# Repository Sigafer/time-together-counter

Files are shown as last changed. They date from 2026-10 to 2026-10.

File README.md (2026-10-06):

# Time-Together Counter

A pocket-watch-sized PCB that shows time passed, from a past moment, in the format `YY:DDD:HH:MM:SS`. The 1.3" OLED (SH1106 128×64 I²C) stays dark until someone double-taps the device. It runs standalone from a small LiPo charged over USB-C every few months.

Designed in Altium Designer by Zsigmond Csaba.

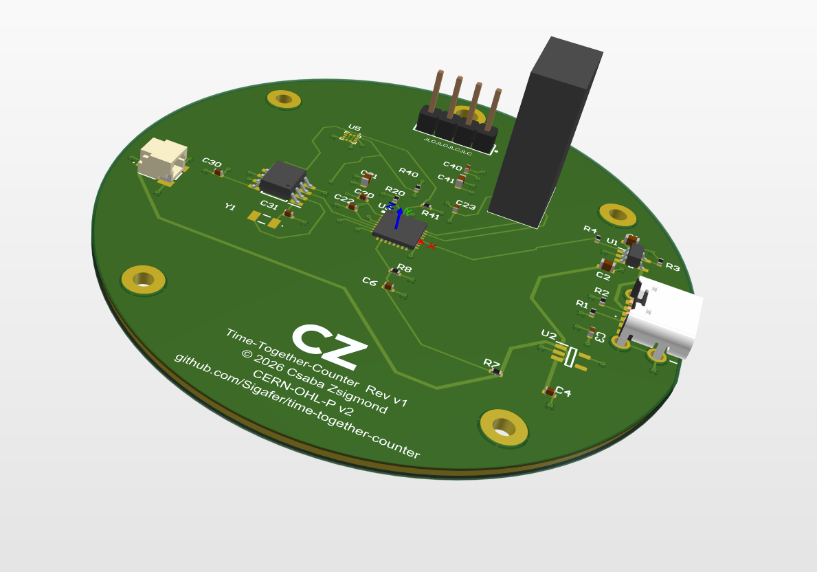
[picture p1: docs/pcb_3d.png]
PCB 3D view


> [!TIP]
> **Schematic and PCB layout:** no Altium needed. Open the PDFs in the [`docs`](docs/) folder:
> - 📄 [Schematic (PDF)](docs/schematic.pdf)
> - 📄 [PCB layout (PDF)](docs/layout.pdf)
> - 📋 [Bill of materials (CSV)](docs/BOM.csv)

## How it works

A low-power STM32 sleeps until the accelerometer detects a double-tap in hardware. It then reads the real-time clock, computes the time elapsed since a fixed start timestamp, and shows it on the OLED for about 5 seconds before going back to sleep. The RTC keeps counting the whole time, so the count survives resets and never drifts more than a few seconds per year.

| Block | Part | Notes |
| --- | --- | --- |
| MCU | STM32L031K6U6 | ~1 µA in Stop mode, programmed over SWD (TC2030) |
| Real-time clock | Micro Crystal RV-3028-C7 | 1 Hz tick on CLKOUT, very low drift |
| Wake on double-tap | ST LIS2DW12 | Tap detection in hardware, INT1 wakes the MCU |
| Display | 1.3" 128×64 SH1106 I²C OLED module | Always on 3V3, put to sleep between taps |
| Charger | Microchip MCP73831 (4.2 V) | 100 mA charge current, status read by the MCU |
| Regulator | TI TPS7A0233 (3.3 V) | 25 nA quiescent current |
| Battery | 502030 protected LiPo, ~250 mAh | JST SH 2-pin connector |
| Charging port | GCT USB4125-GF-A | USB-C, power only (5.6k CC pull-downs) |

### I²C addresses

| Device | Address |
| --- | --- |
| RV-3028-C7 (RTC) | 0x52 |
| LIS2DW12 (accelerometer) | 0x18 |

## Repository layout

```
hardware/altium/            Altium project: .PrjPcb and .SchDoc
hardware/altium/libraries/  component libraries used by the project (.SchLib, .PcbLib)
hardware/production/        Gerbers, BOM and pick-and-place files (later)
firmware/                   STM32 firmware (later)
docs/                       schematic PDF and other documentation
artwork/                    line art for the black art side of the board (later)
mechanical/                 3D-printed back cover (later)
```

## License

   Copyright 2026 Csaba Zsigmond

   This hardware design is licensed under the CERN Open Hardware Licence
   Version 2 – Permissive (CERN-OHL-P v2). See [LICENSE](LICENSE).

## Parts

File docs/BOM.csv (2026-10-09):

Comment | Description | Designator | Footprint | Quantity | Manufacturer | Manufacturer Part Number | LCSC | Fitted
4.7uF | Ceramic capacitor 4.7uF 10V X5R 0603 | C1, C2, C21 | 0603 | 3 | Yageo | CC0603KRX5R6BB475 | C109456 | Yes
1uF | Ceramic capacitor 1uF 25V X5R 0402 | C3, C4 | 0402 | 2 | Samsung Electro-Mechanics | CL05A105KA5NQNC | C52923 | Yes
100nF | Ceramic capacitor 100nF 16V X7R 0402 | C6, C20, C22, C23, C30, C40 | 0402 | 6 | Yageo | CC0402KRX7R7BB104 | C60474 | Yes
10uF | Ceramic capacitor 10uF 10V X5R 0603 | C41 | 0603 | 1 | Samsung Electro-Mechanics | CL10A106KP8NNNC | C19702 | Yes
20pF C0G | Ceramic capacitor 20pF 50V C0G 0402, RTC crystal load (OSCI) | C31 | 0402 | 1 | FH | 0402CG200J500NT | C1554 | Yes
5.1k | Resistor 5.1k 1% 0402, USB-C CC pull-down | R1, R2 | 0402 | 2 | UNI-ROYAL | 0402WGF5101TCE | C25905 | Yes
10k | Resistor 10k 1% 0402 | R3, R4, R20 | 0402 | 3 | UNI-ROYAL | 0402WGF1002TCE | C25744 | Yes
1M | Resistor 1M 1% 0402, battery divider | R7, R8 | 0402 | 2 | UNI-ROYAL | 0402WGF1004TCE | C26083 | Yes
4.7k | Resistor 4.7k 1% 0402, I2C pull-up | R40, R41 | 0402 | 2 | UNI-ROYAL | 0402WGF4701TCE | C25900 | Yes
MCP73831T-2ACI/OT | LiPo charger 4.2V, 100mA | U1 | SOT-23-5 | 1 | Microchip | MCP73831T-2ACI/OT | C424093 | Yes
TPS7A0233DBVR | LDO 3.3V 200mA, 25nA Iq | U2 | SOT-23-5 | 1 | Texas Instruments | TPS7A0233DBVR | C5142805 | Yes
STM32L031K6U6 | MCU Cortex-M0+ 32kB flash | U3 | UFQFPN-32 5x5 | 1 | STMicroelectronics | STM32L031K6U6TR | C2969821 | Yes
BM8563ESA | RTC I2C (PCF8563-compatible) | U4 | SOP-8 | 1 | Gatemode | BM8563ESA | C269877 | Yes
LIS2DW12TR | Accelerometer, double-tap wake | U5 | LGA-12 2x2 | 1 | STMicroelectronics | LIS2DW12TR | C189624 | Yes
32.768kHz 12.5pF | Crystal 32.768kHz 12.5pF +/-20ppm | Y1 | 3215 (3.2x1.5mm) | 1 | Epson | Q13FC13500004 | C32346 | Yes
USB4125-GF-A | USB-C receptacle, power only (6P) | J1 | USB4125-GF-A | 1 | GCT | USB4125-GF-A | C3151650 | Yes
SM02B-SRSS-TB(LF)(SN) | JST SH 2-pin side entry, LiPo | J2 | SM02B-SRSS-TB | 1 | JST | SM02B-SRSS-TB(LF)(SN) | C160402 | Yes
TC2030-IDC-NL | SWD programming pads (no part, cable only) | J3 | TC2030-IDC-NL | 1 | Tag-Connect | TC2030-IDC-NL |  | No
OLED header | 1x4 2.54mm header, comes with SH1106 OLED module, hand-soldered | J4 | 1x4 THT 2.54mm | 1 |  |  |  | No

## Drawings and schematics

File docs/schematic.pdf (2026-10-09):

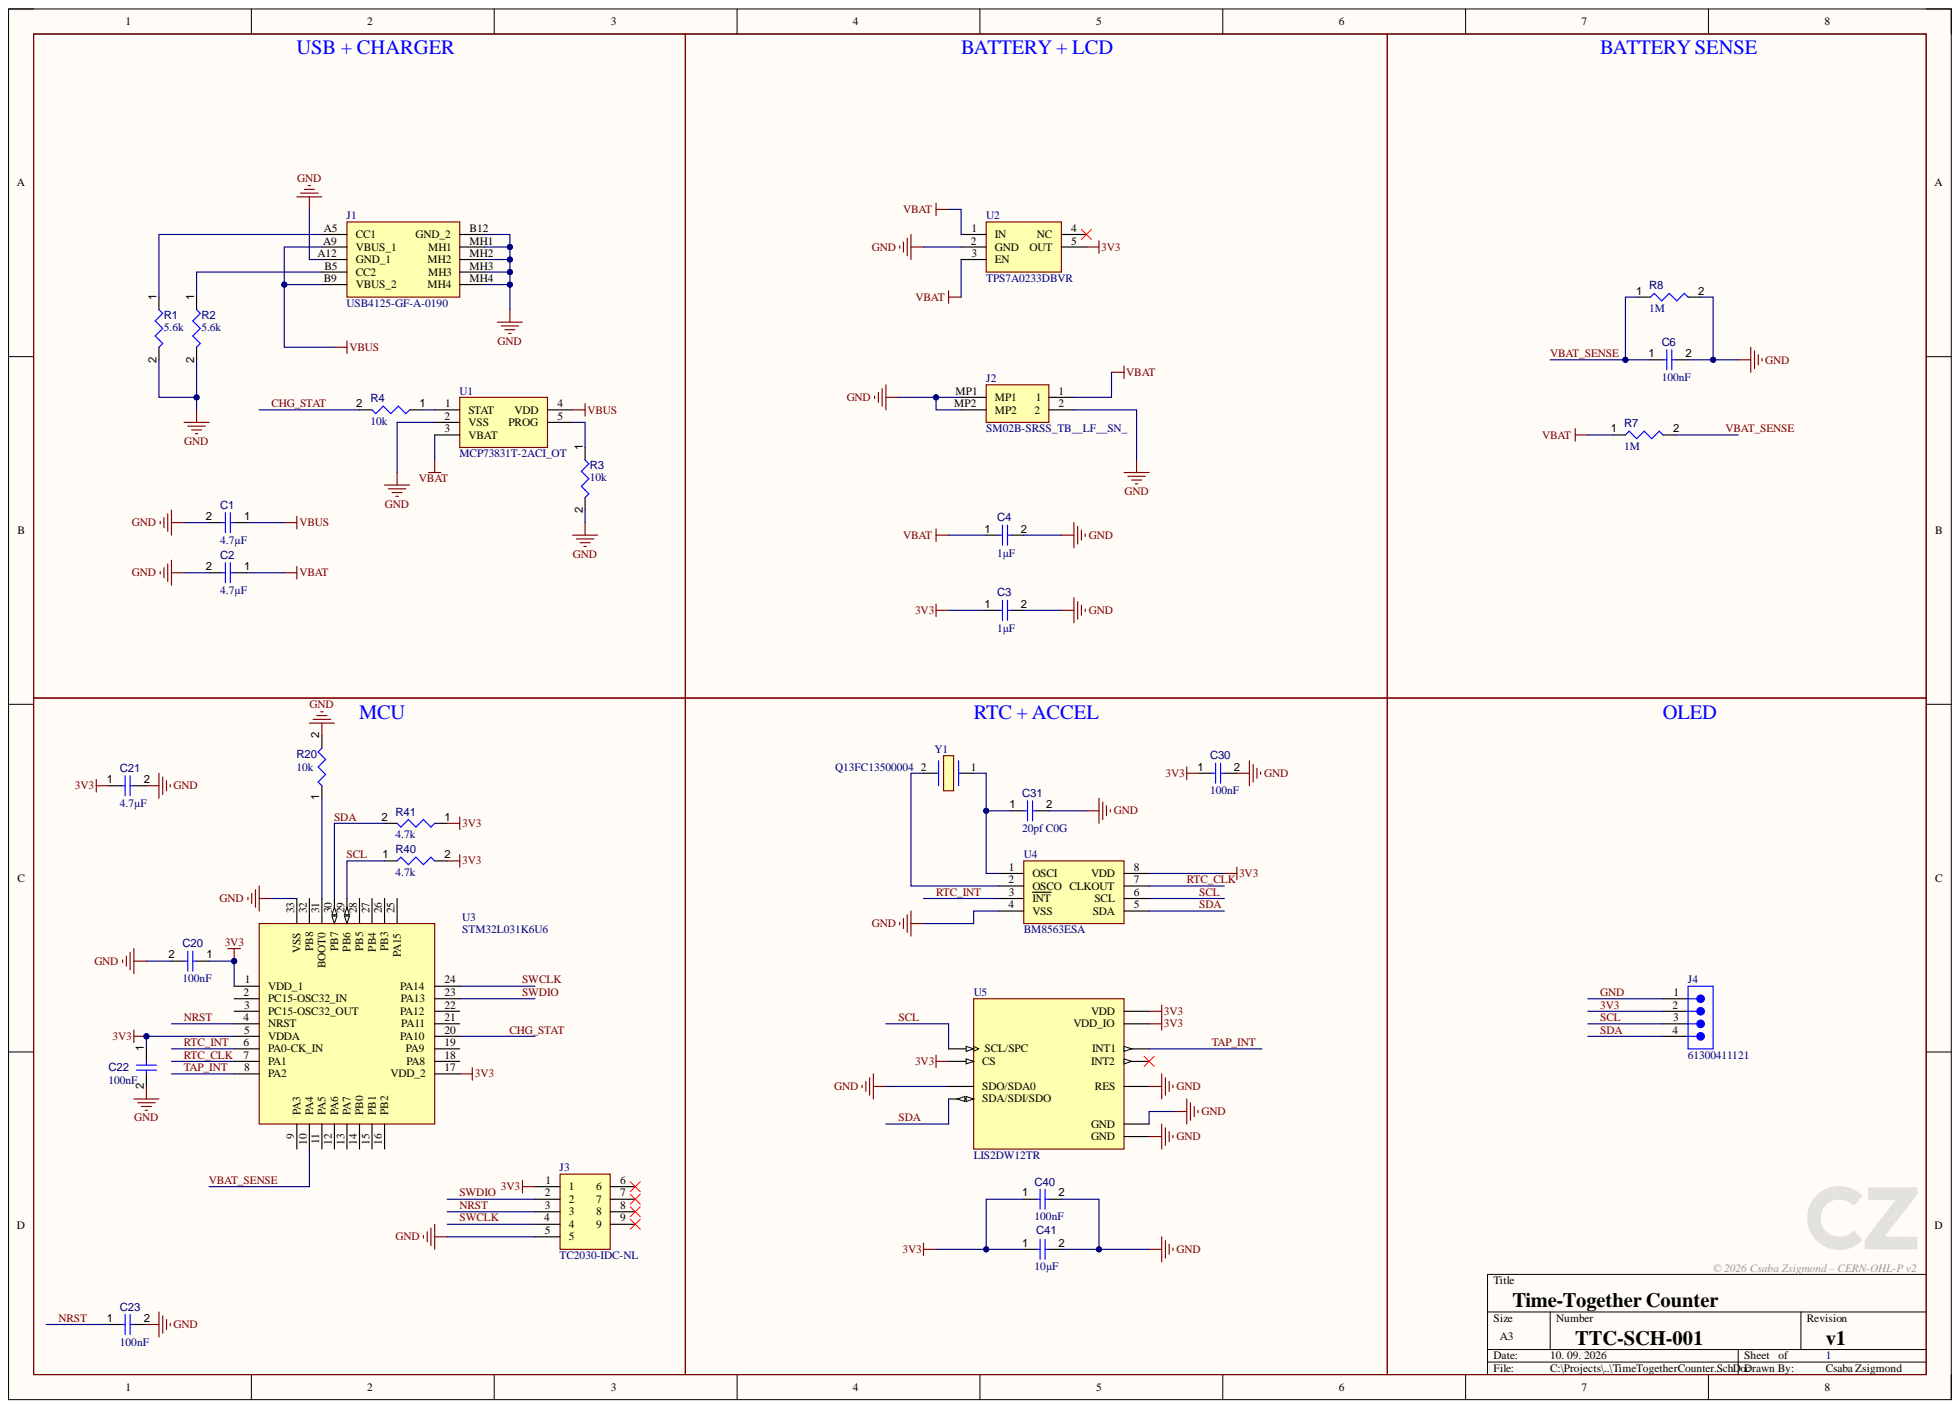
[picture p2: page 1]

© 2026 Csaba Zsigmond – CERN-OHL-P v2

Size A3 | Number TTC-SCH-001 | Revision v1

Date: 10. 09. 2026 | Sheet of 1
File: C:\Projects\..\TimeTogetherCounter.SchDoDc rawn By: | Csaba Zsigmond

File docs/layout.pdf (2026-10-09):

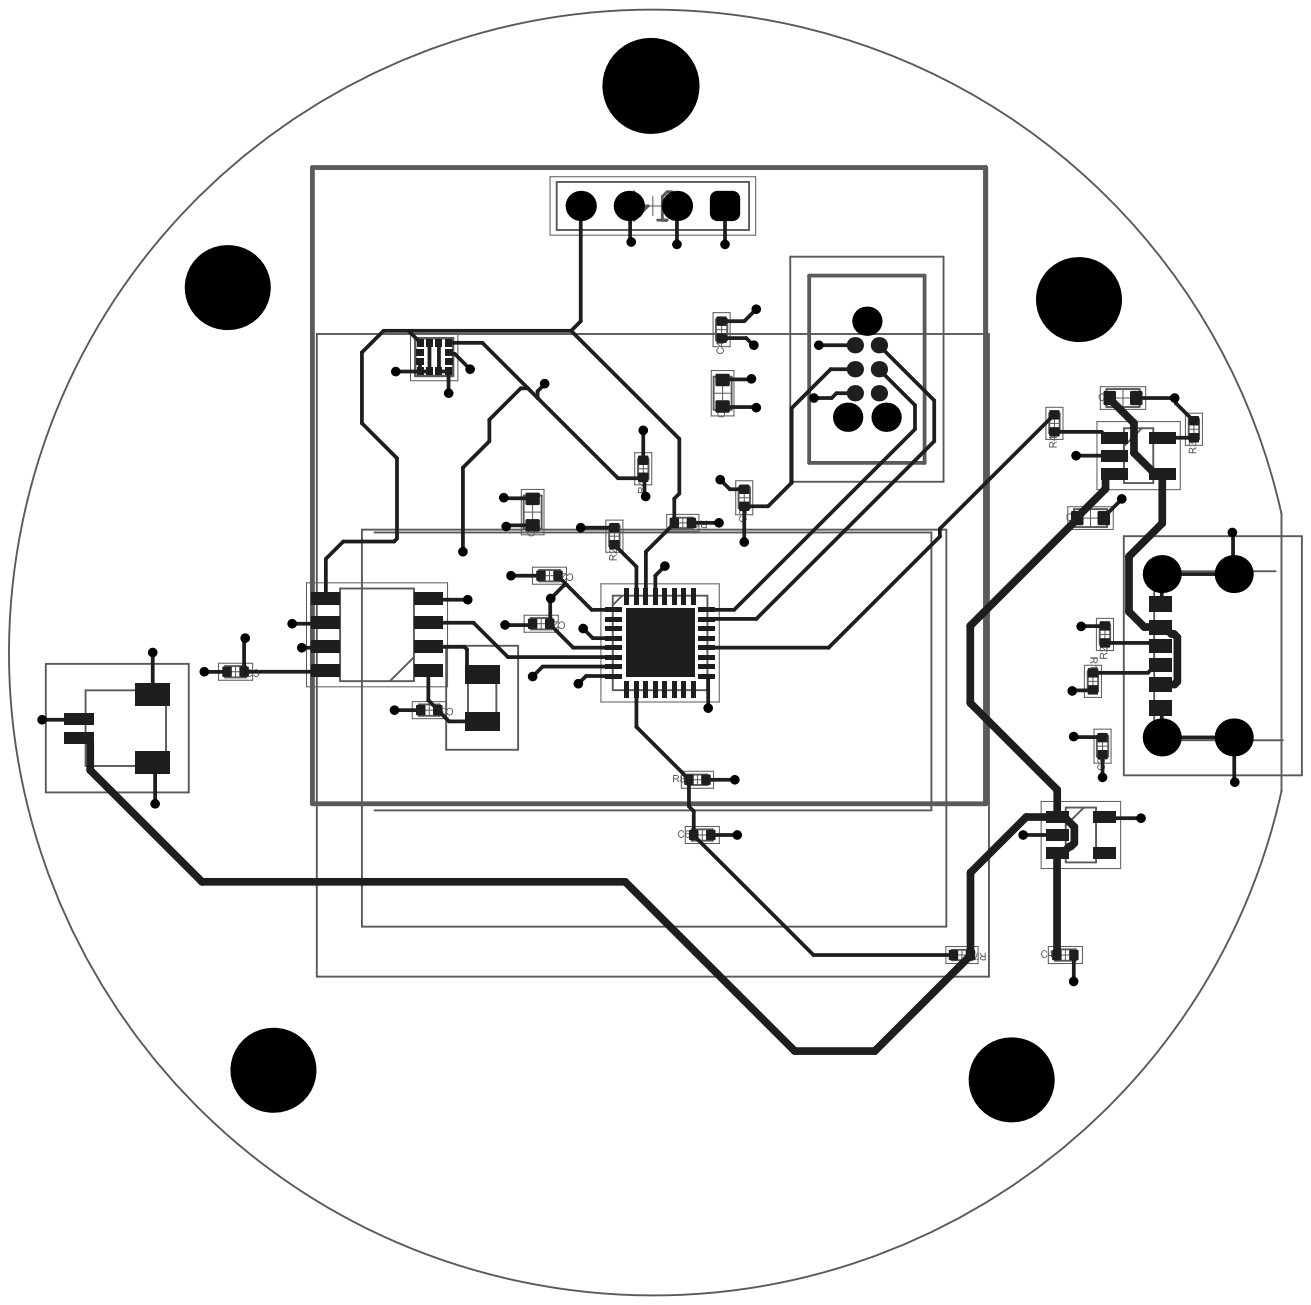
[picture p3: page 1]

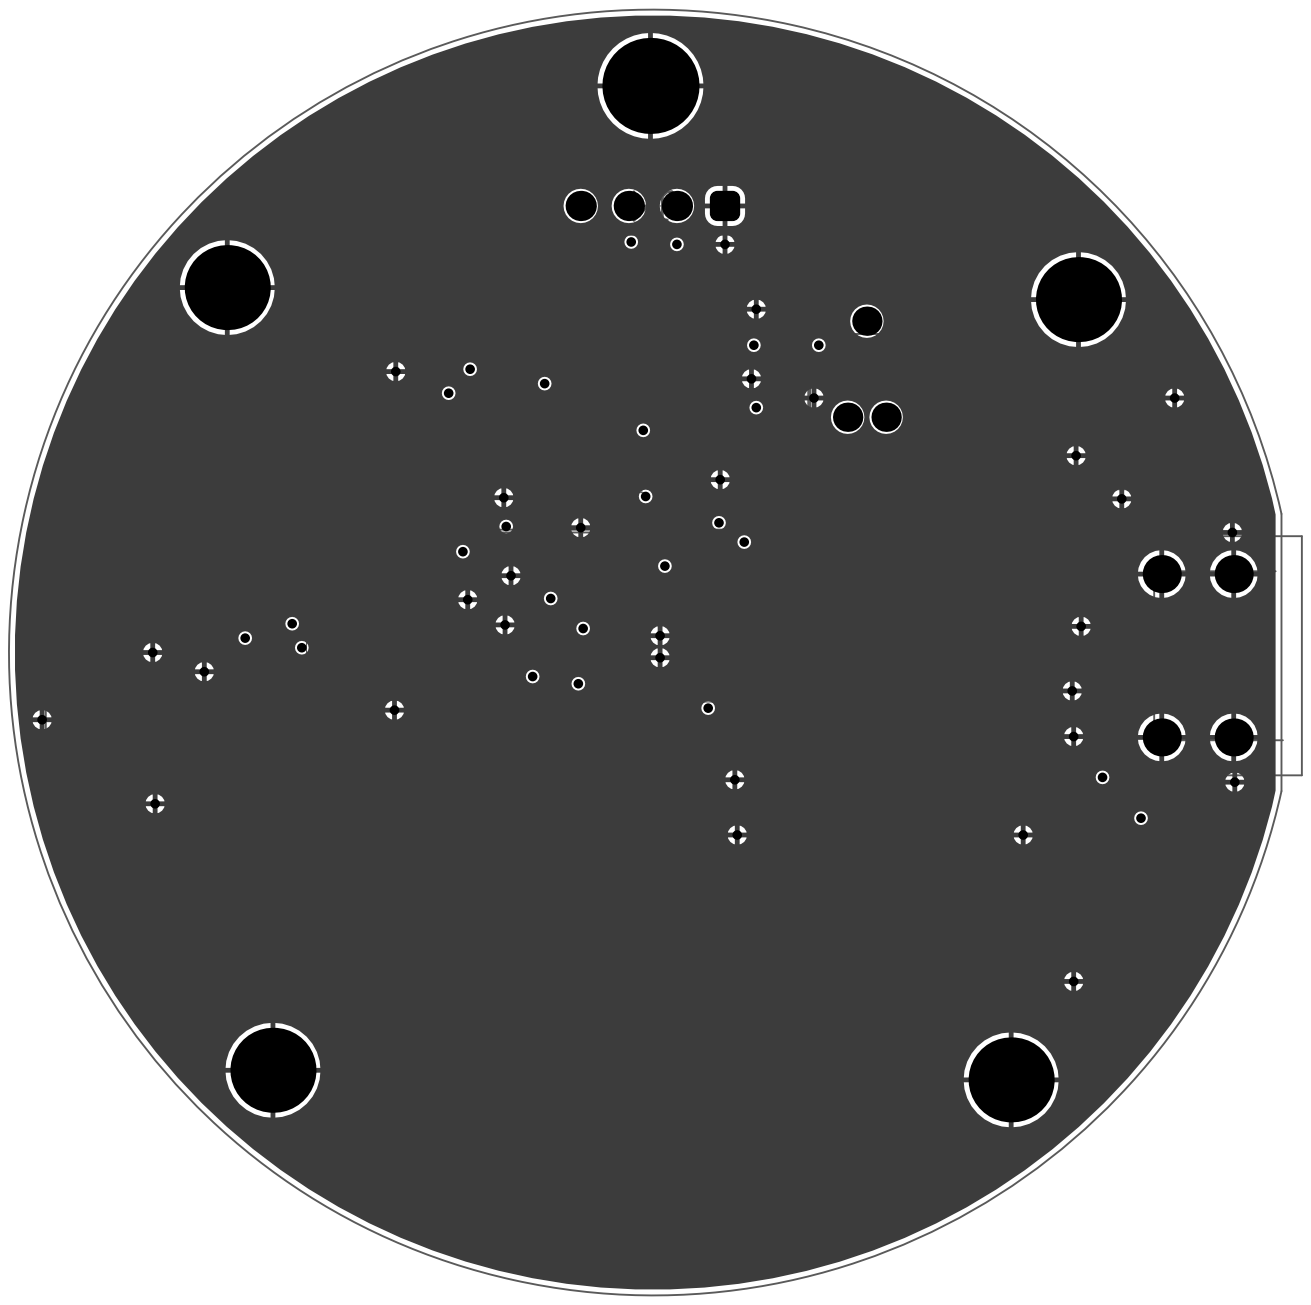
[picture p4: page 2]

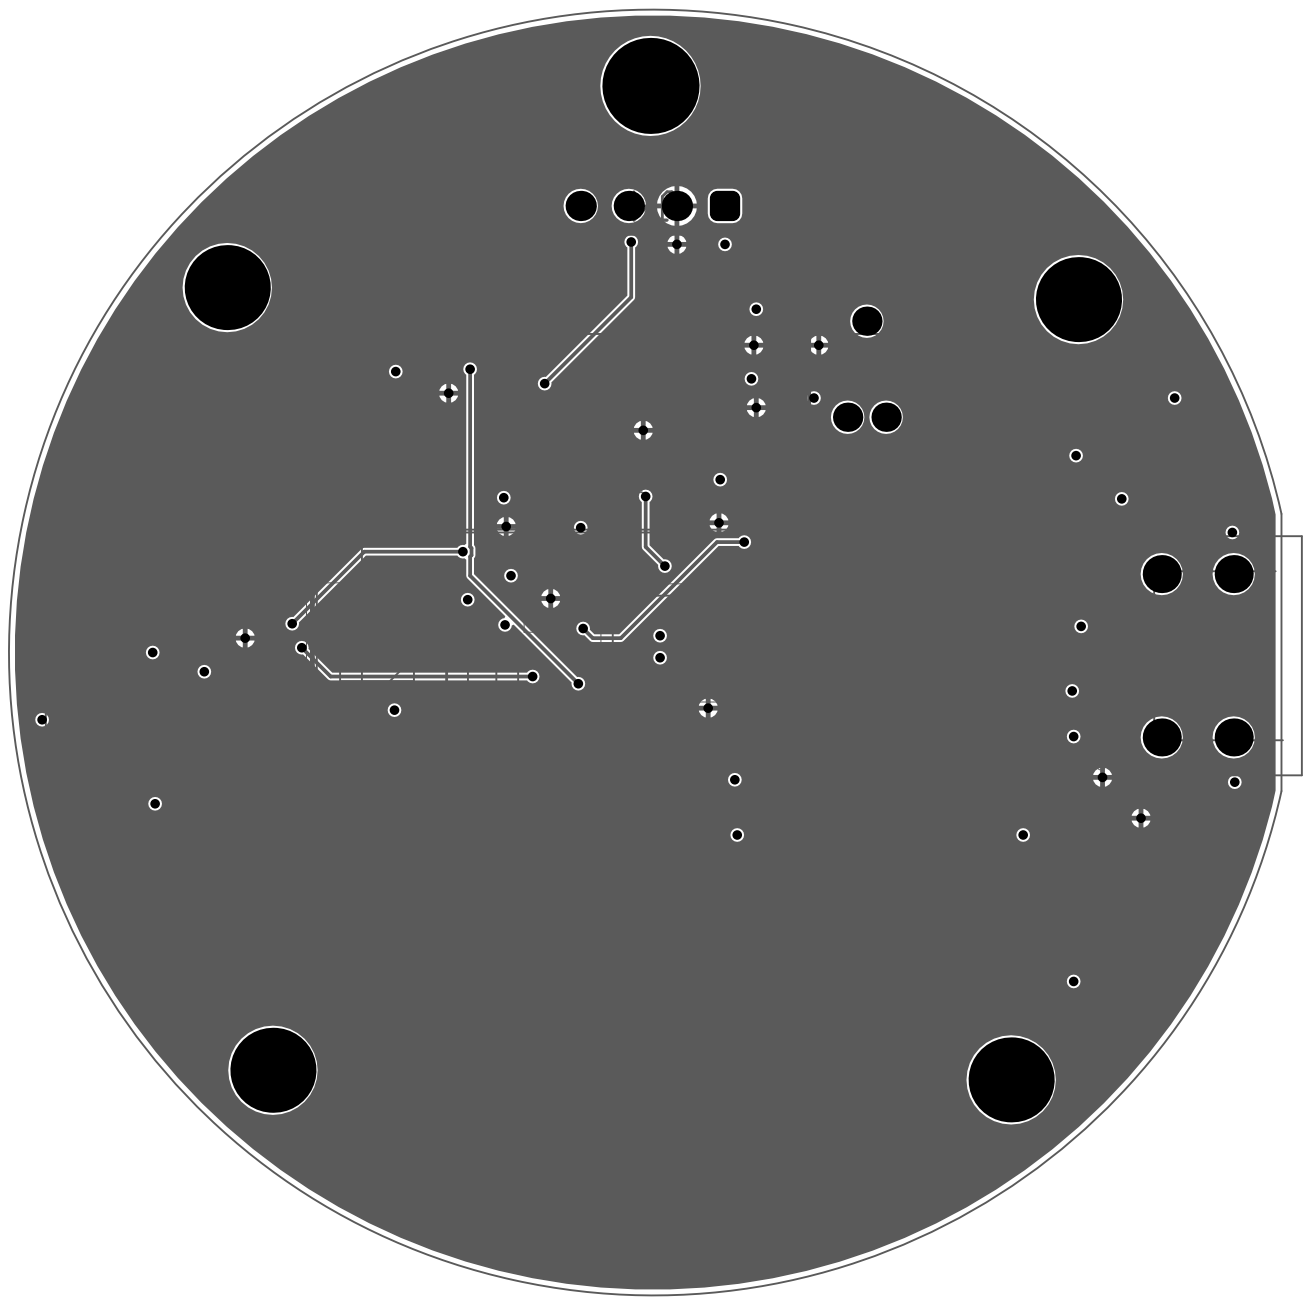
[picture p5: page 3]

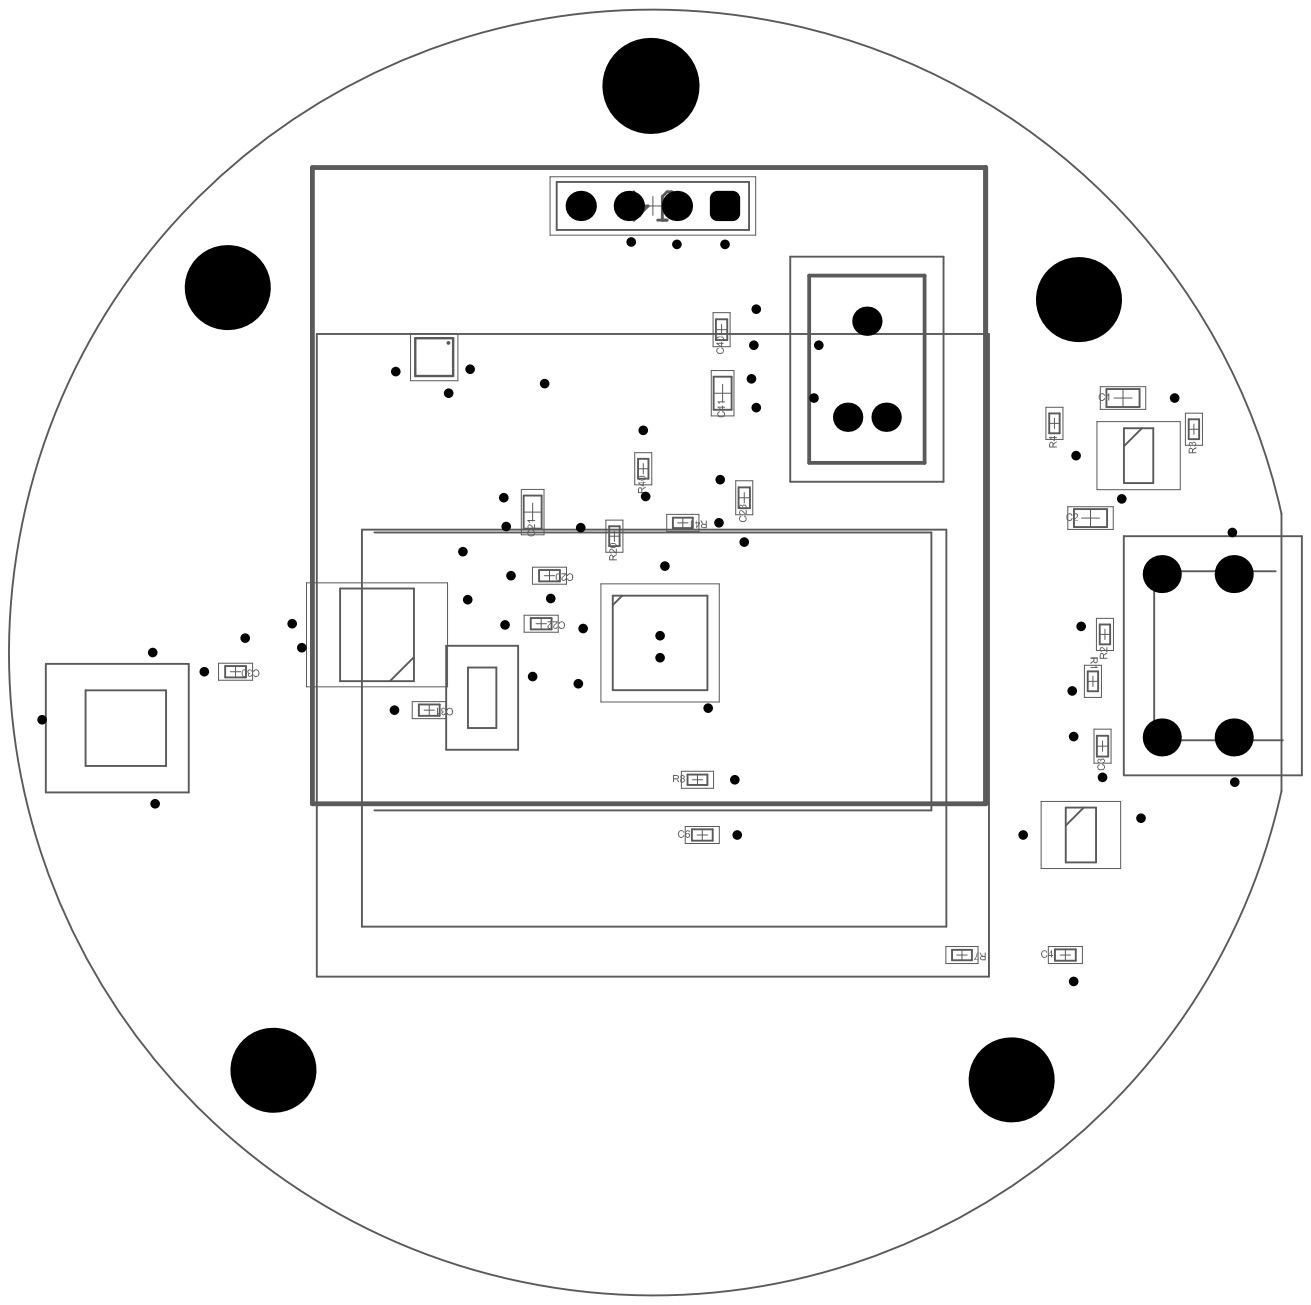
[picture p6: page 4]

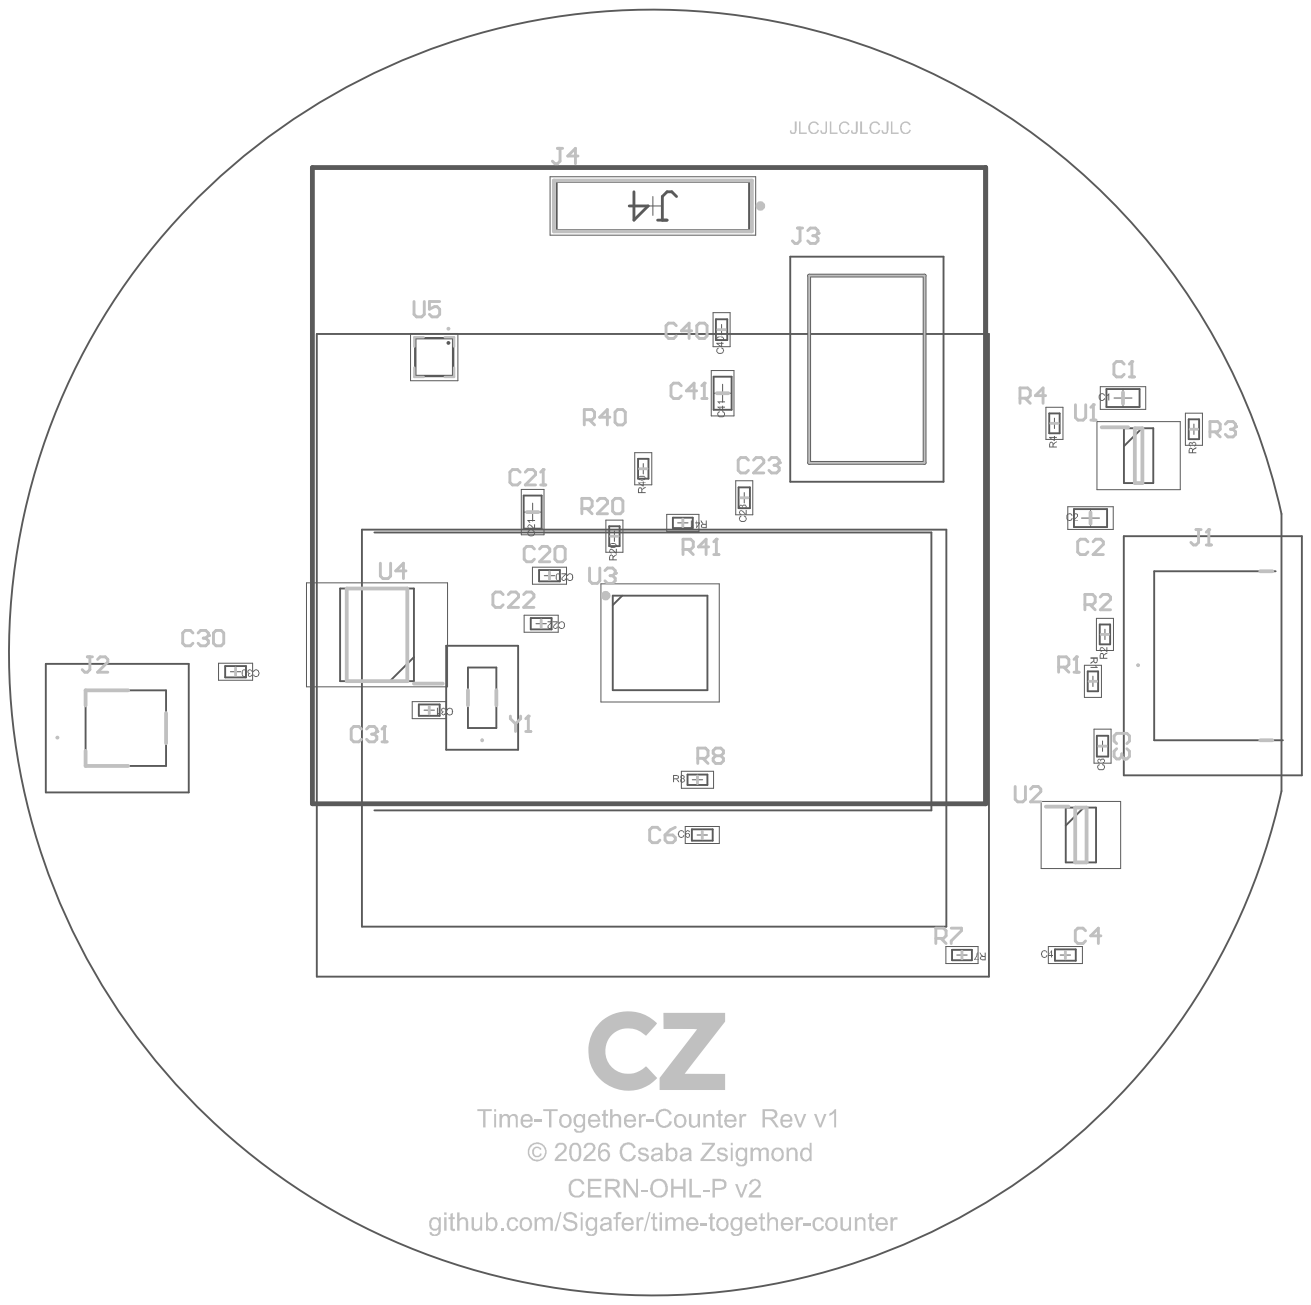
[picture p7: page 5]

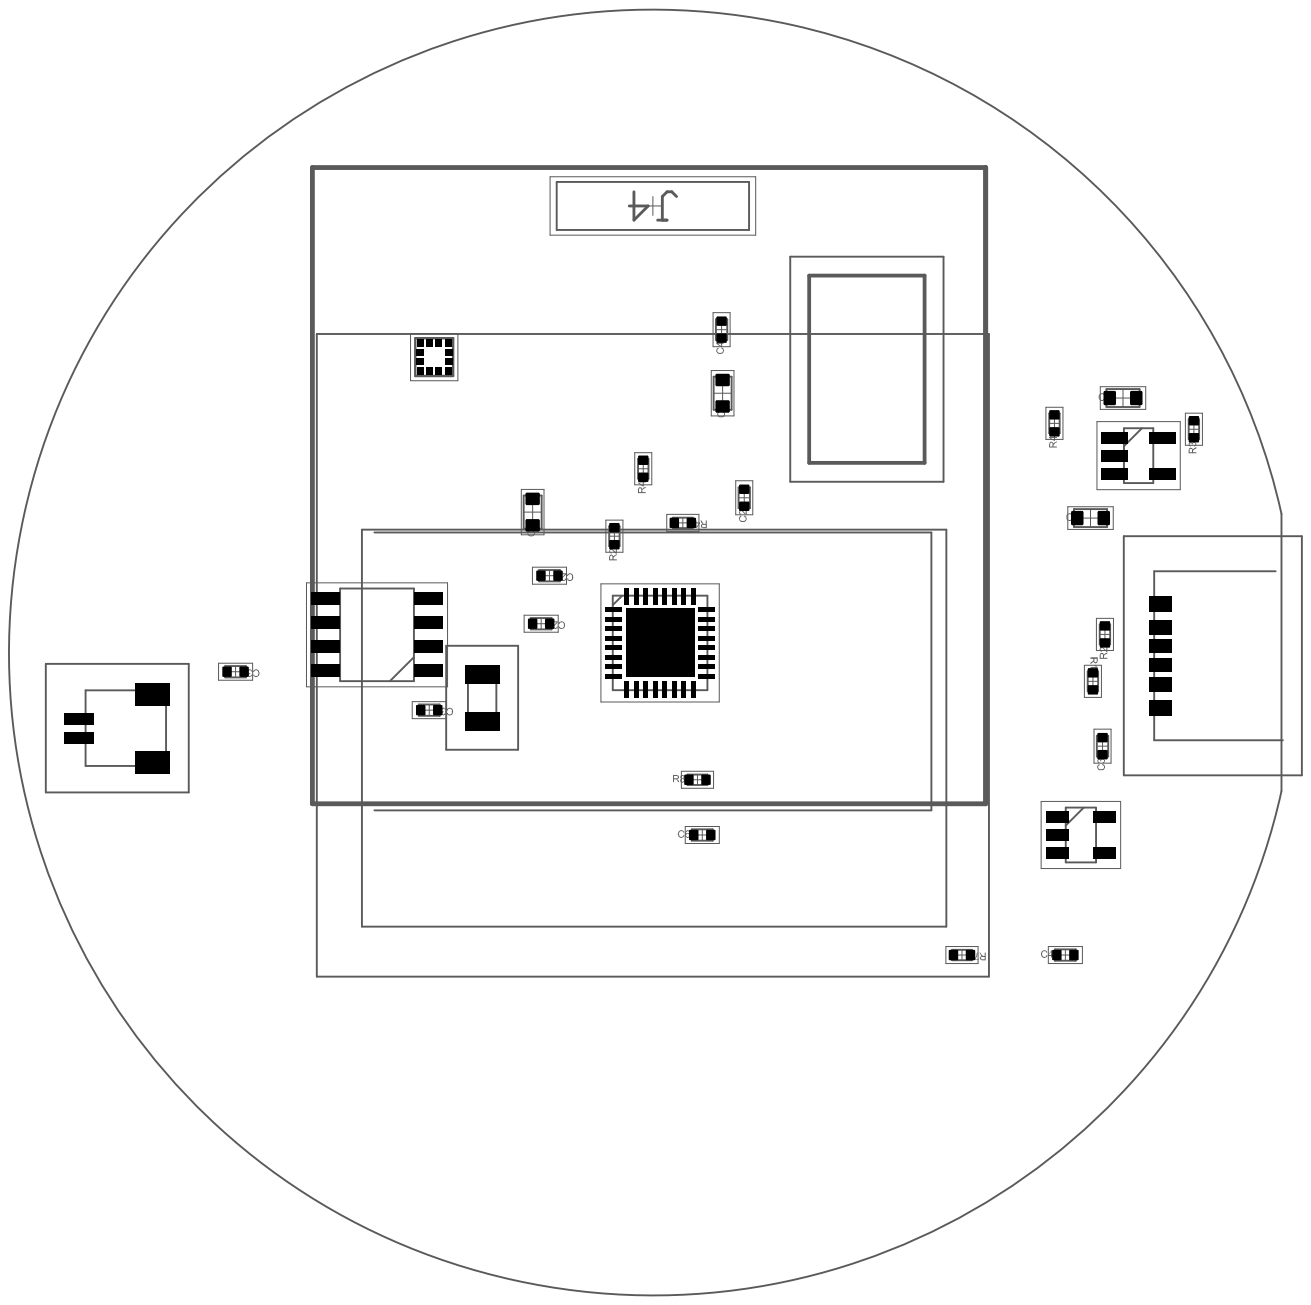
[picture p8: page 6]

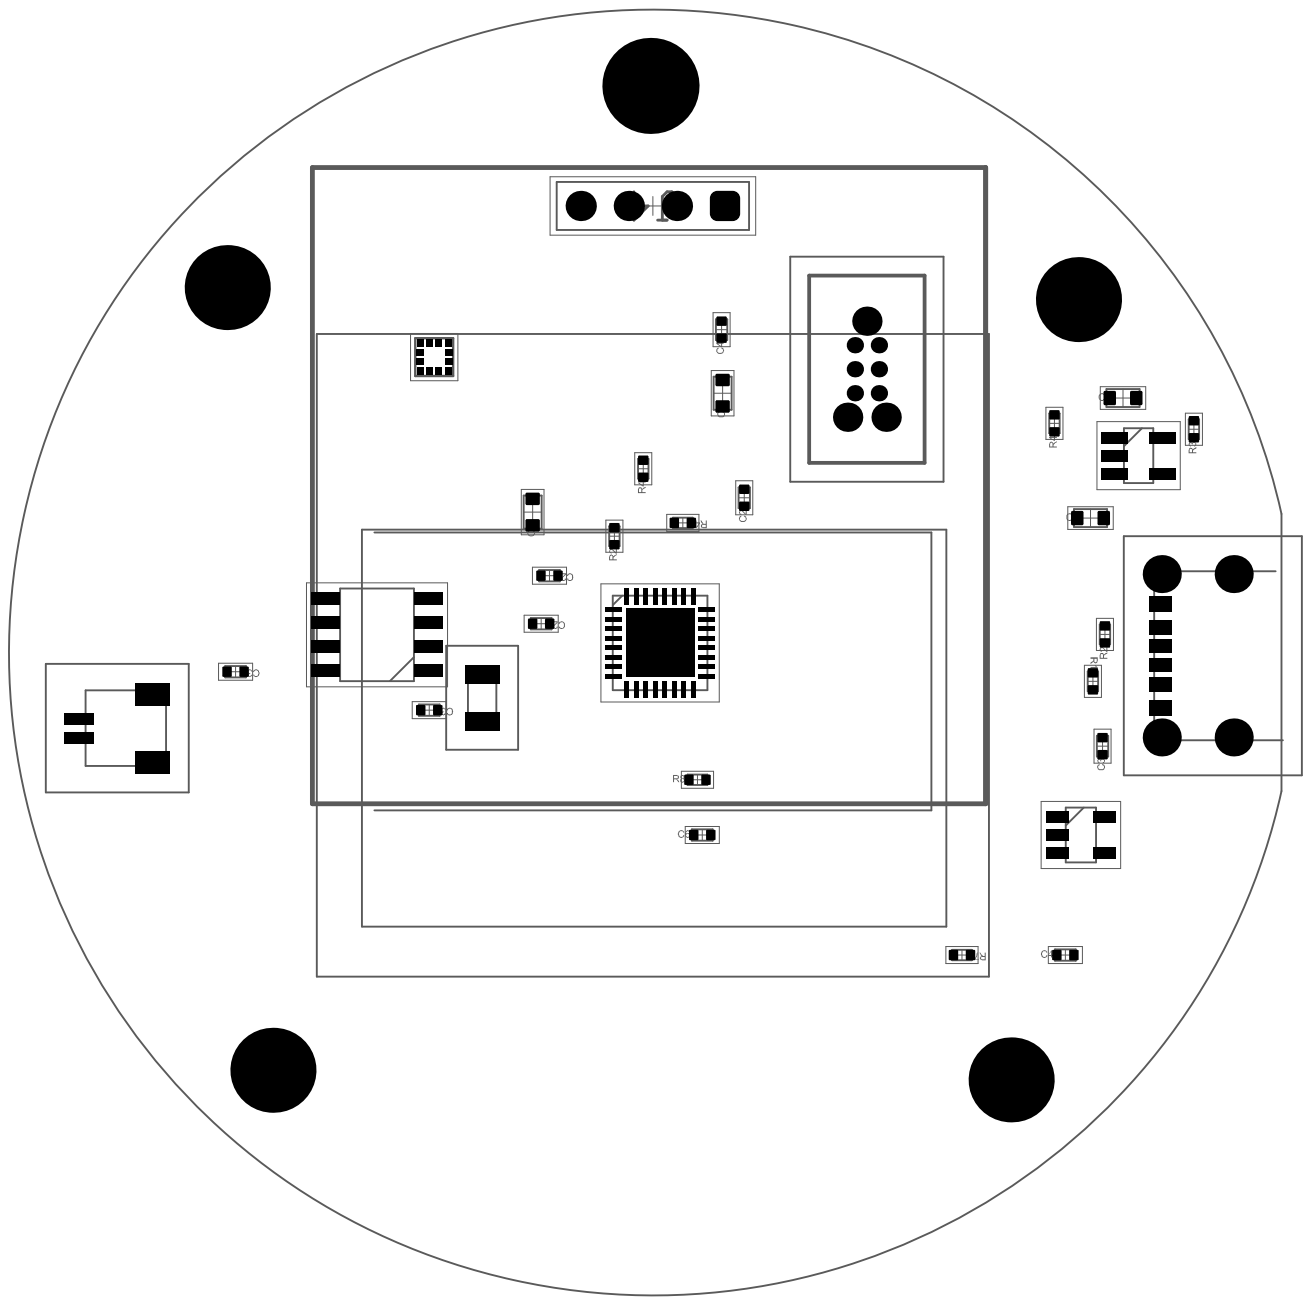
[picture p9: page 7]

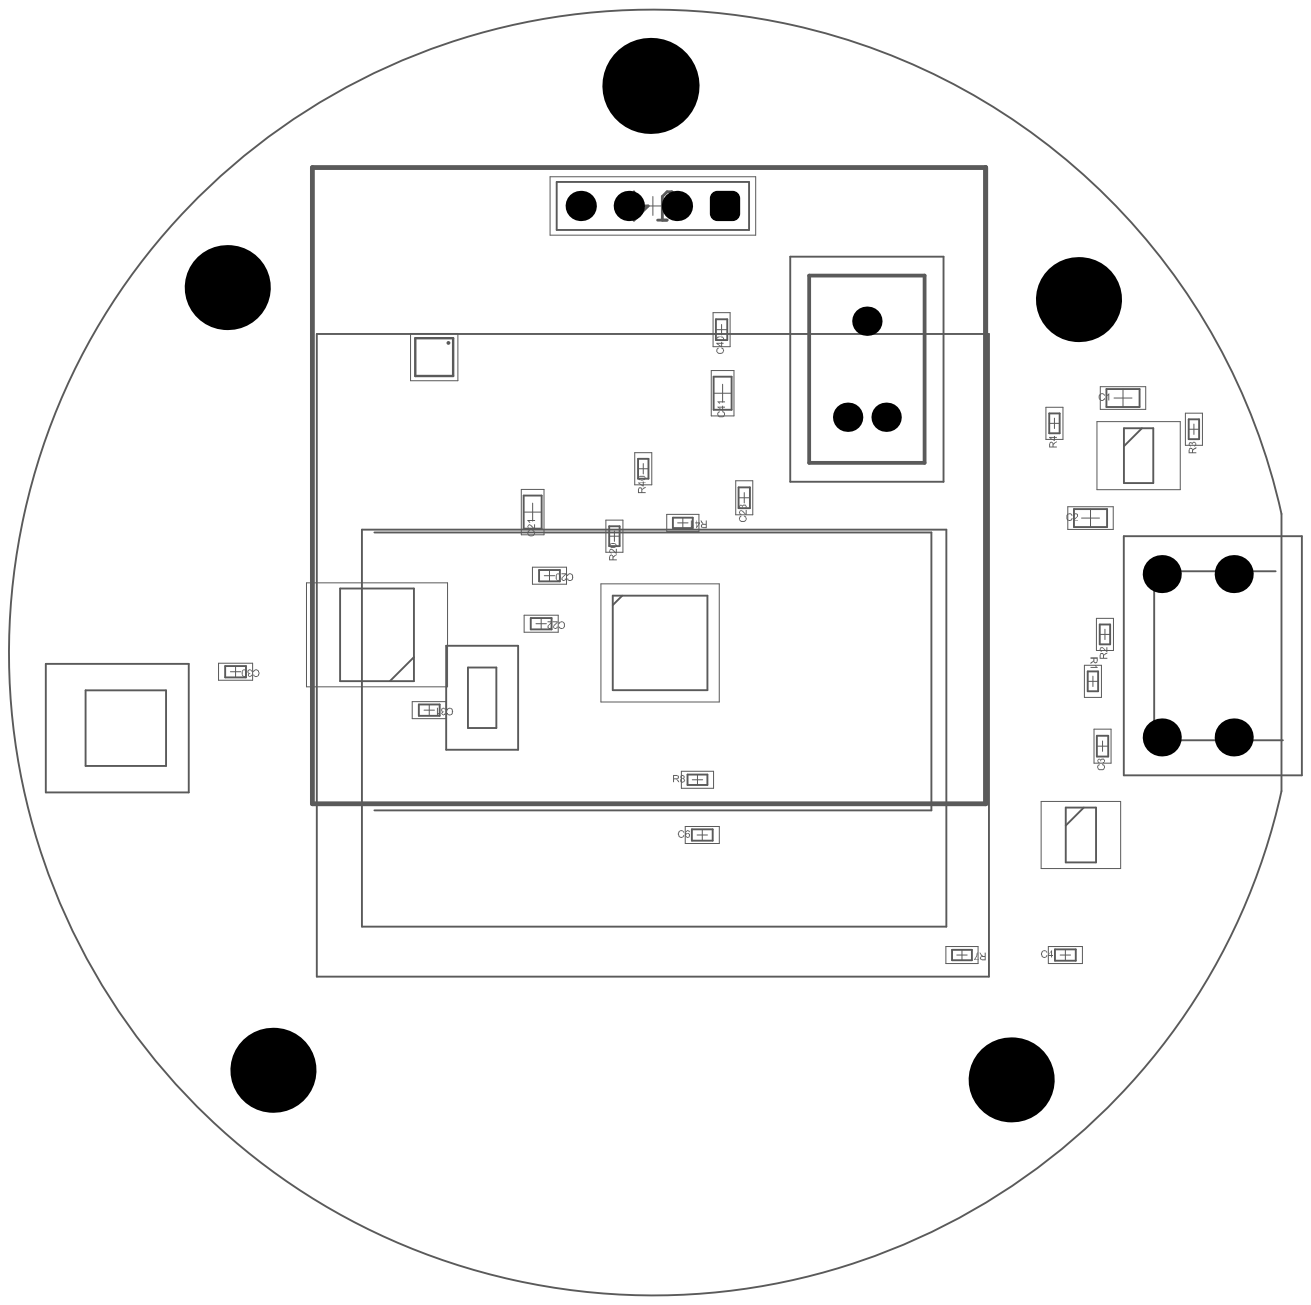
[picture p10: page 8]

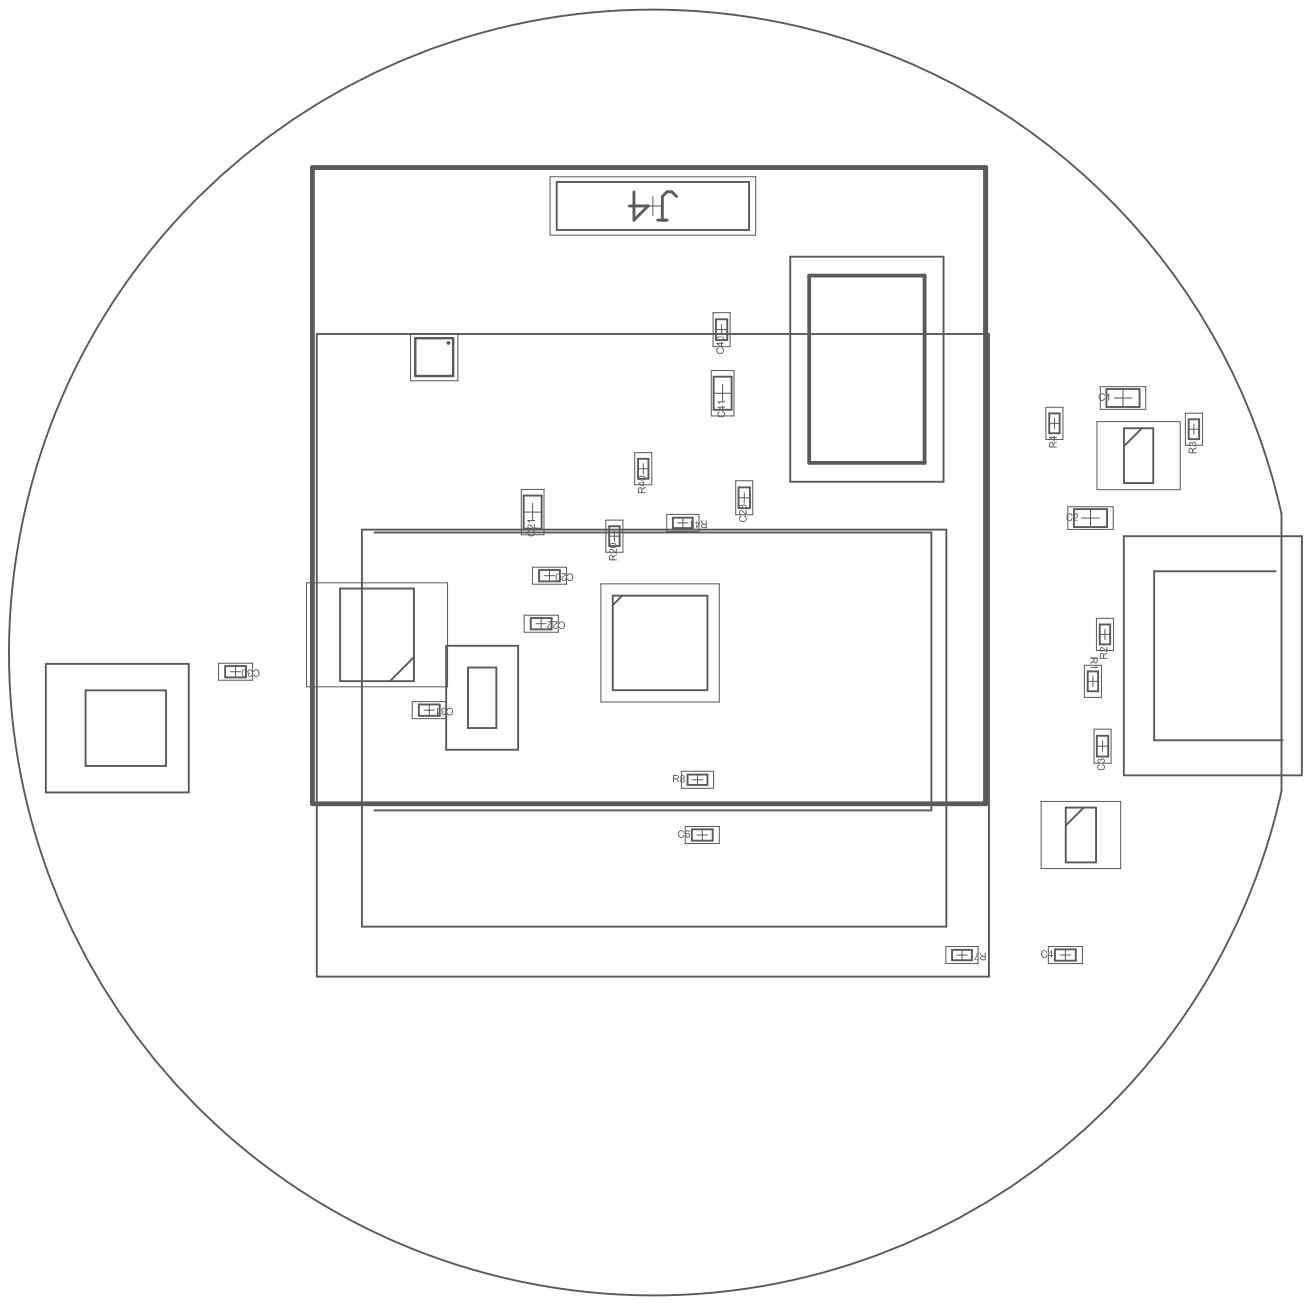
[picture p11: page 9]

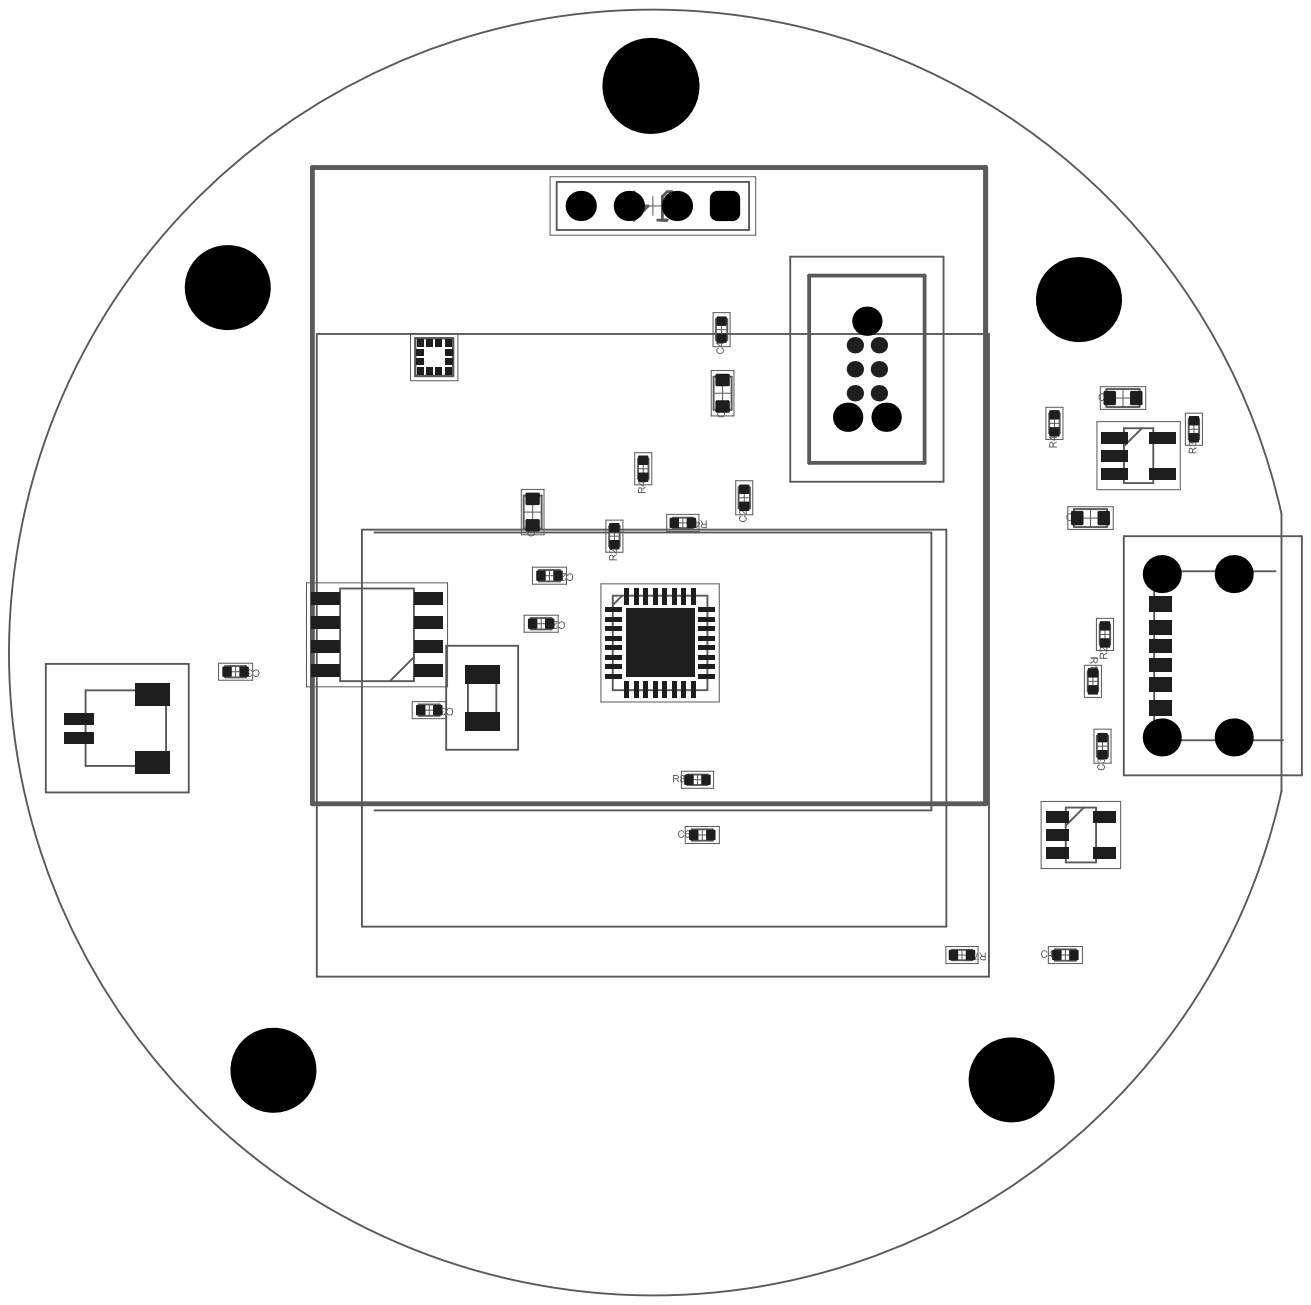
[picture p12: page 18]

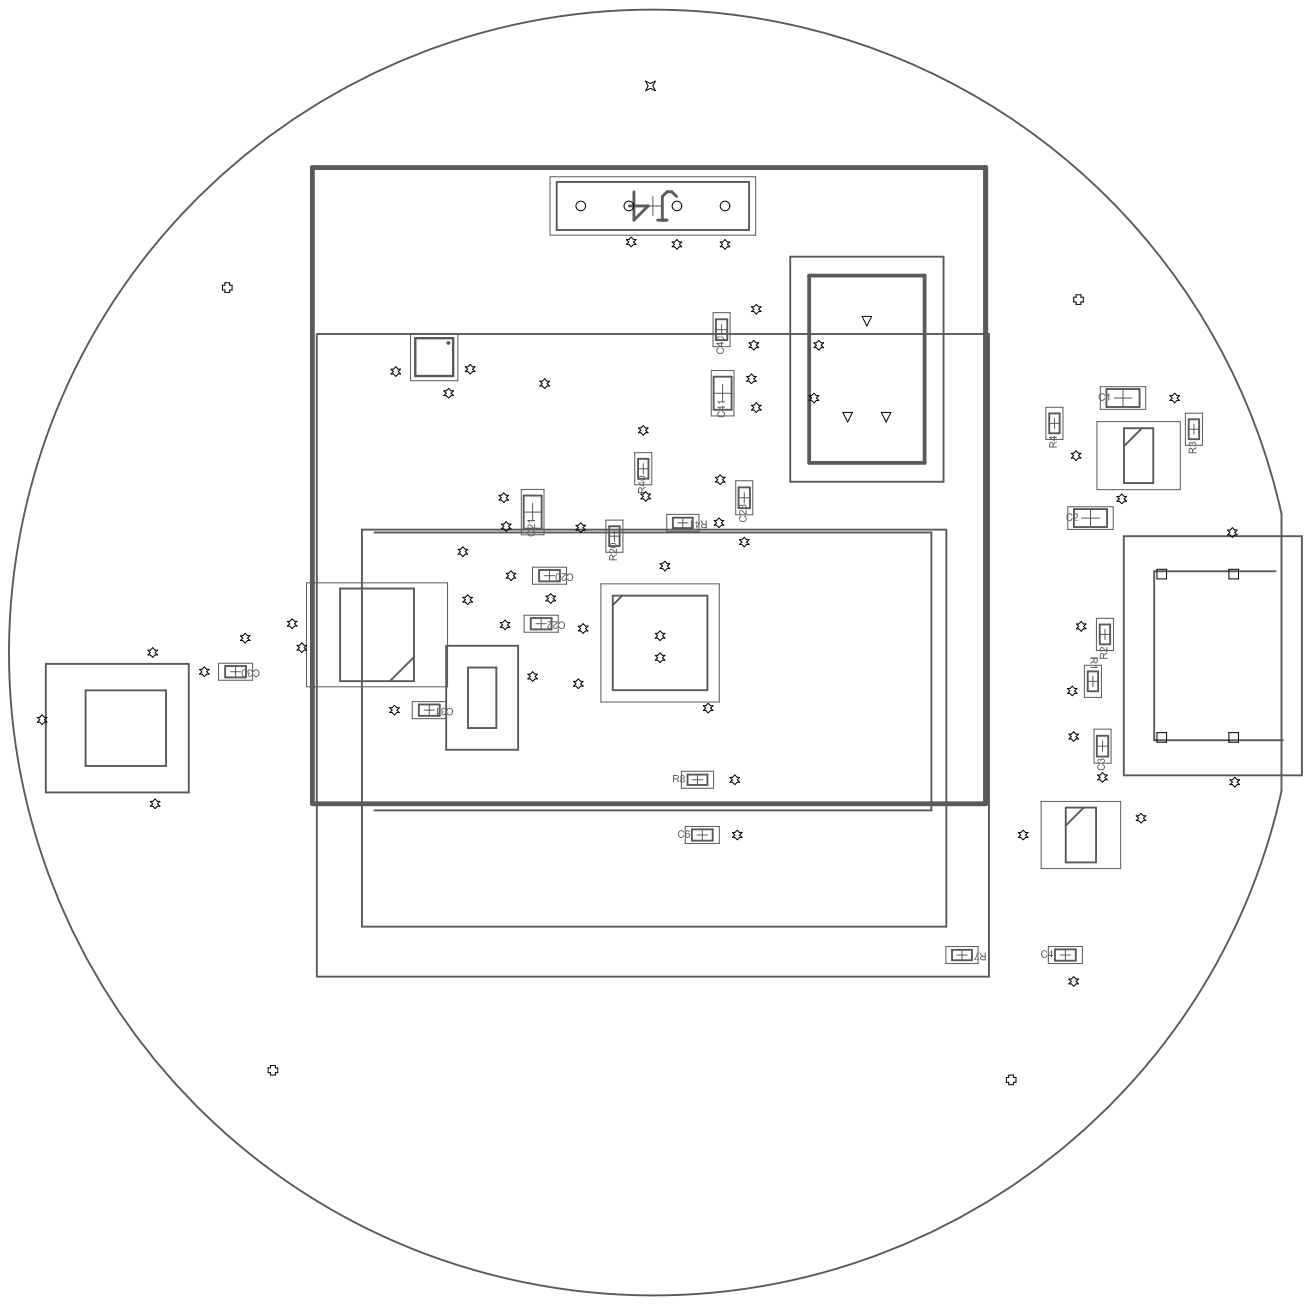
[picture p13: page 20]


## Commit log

2026-10-05 Schematic Rev v1
    Complete schematic: power, MCU, RTC, accelerometer, OLED module header. Compiles with no errors.
    [Time-Together-Counter.PrjPcb, TimeTogetherCounter.SchDoc]
2026-10-05 Add license notice to schematic
    [TimeTogetherCounter.SchDoc]
2026-10-05 PCB:placement, 4 layer stack, JLC rules, GND/3V3 planes
    [Time-Together-Counter.PrjPcb, TimeTogetherCounter.PcbDoc, TimeTogetherCounter.SchDoc]
2026-10-06 PCB routed, DRC clean
    [TimeTogetherCounter.PcbDoc, TimeTogetherCounter.SchDoc]
2026-10-06 Cleanup, Branding, Mounting Holes, 3D, layout pdf, BOM
    [BOM.csv, TimeTogetherCounter.PcbDoc, TimeTogetherCounter.SchDoc]
2026-10-06 Fatal MCU wiring fixed
    [Time-Together-Counter.PrjPcb, TimeTogetherCounter.PcbDoc, TimeTogetherCounter.SchDoc]
2026-10-06 Date added
    [TimeTogetherCounter.PcbDoc]
2026-10-06 date added_better
    [TimeTogetherCounter.PcbDoc]
2026-10-06 adjusted mounting holes unevenly
    [TimeTogetherCounter.PcbDoc]
2026-10-06 Gerber files + text flip on bottom
    [Time-Together-Counter.PrjPcb, TimeTogetherCounter.PcbDoc]
2026-10-06 Added gerber files
    [TimeTogetherCounter.GBL, TimeTogetherCounter.GBO, TimeTogetherCounter.GBP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]
2026-10-09 Replace RV-3028 RTC with BM8563 + crystal
    - RV-3028-C7 out of stock everywhere -> U4 now BM8563ESA
    (PCF8563-compatible, SOP-8, LCSC C269877)
    - Added Y1: Epson FC-135 32.768 kHz 12.5 pF crystal (LCSC C32346)
    - Added C31: 20 pF C0G load cap on OSCI (LCSC C1554)
    - Removed R30 (no VBACKUP pin on the new RTC)
    - Re-routed U4 area, removed stray tracks on GND layer
    - Silkscreen rules set to JLCPCB limits (6 mil), designators resized
    - DRC clean (only footprint silk trimming warnings left)
    [Time-Together-Counter.PrjPcb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]
2026-10-09 updated docs folder accordingly
    [BOM.csv]
2026-10-09 updated production files
    [TimeTogetherCounter.PcbDoc]
2026-10-09 Wired J4
    [TimeTogetherCounter.PcbDoc, TimeTogetherCounter.SchDoc]
2026-10-09 updated documentation
    [TimeTogetherCounter.SchDoc]
